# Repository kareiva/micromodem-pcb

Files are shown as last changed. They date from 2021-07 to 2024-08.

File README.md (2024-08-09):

# LY2EN-made MicroModem Arduino Nano shield

PCB and schematics for a very basic [MicroModem](https://unsigned.io/micromodem/) shield for Arduino Nano to use with Baofeng radios.

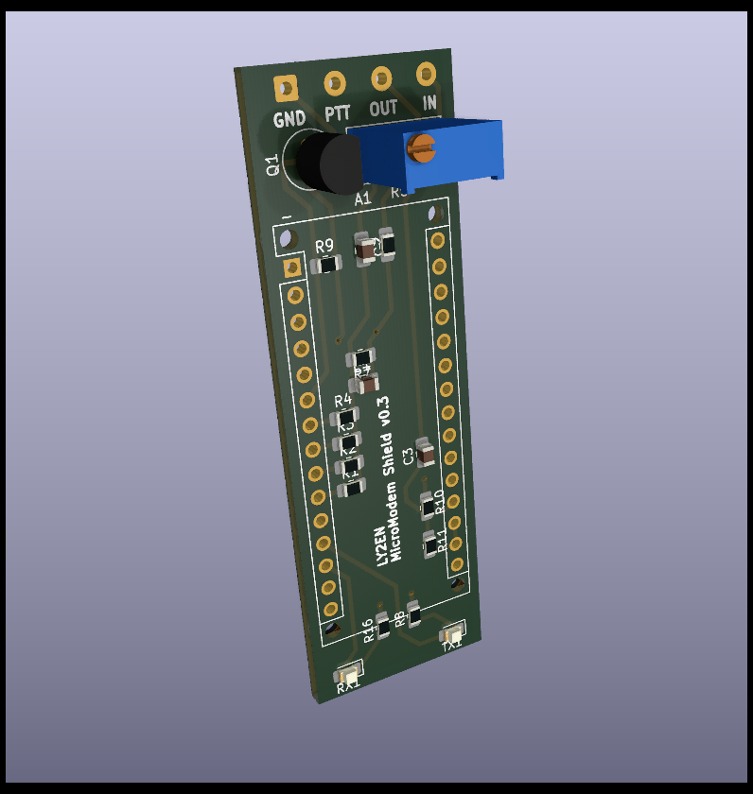
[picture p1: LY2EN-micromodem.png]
LY2EN-micromodem


## Disclaimer

This is experimental work. The authors do not hold any responsibility for any damage to your electronics components, wiring or other property when using this prototype. Use at your own risk.

## How to use

1. Upload the [MicroAPRS 3v KISS firmware](https://github.com/markqvist/MicroAPRS/raw/master/precompiled/microaprs-3v-kiss-latest.hex) to the Arduino Nano:

    avrdude -p m328p -c arduino -P /dev/ttyUSB0 -b 115200 -U flash:w:microaprs-3v-kiss-latest.hex

2. Plug the Arduino Nano into your Android phone's USB host

3. Launch [APRSDroid](https://aprsdroid.org/) 

    3.1 Select TNC (KISS) mode over USB. 
    
    3.2 Keep the baud rate at 9600.
    
4. Set the 3296W trimmer to something around 47kOhm. Your resistance might vary here. Once you're confident, you can replace it with a simple 47k resistor.

Verified working with both the MicroAPRS KISS and MicroAPRS SimpleSerial firmware for 3V.

## Cables

If you're not using a [Bluetooth SPP-C module](https://www.aliexpress.com/item/32998624269.html), a USB-C male to USB-A female adapter is required for recent Android smartphones.

Connect to Baofeng radio over [this cable](https://a.aliexpress.com/_mNhKQOm).

### Pinout
The Baofeng cable has two TRS (Tip, Ring, Sleeve) connectors.
#### 3.5mm
* Sleeve - PTT
* Ring - OUT
#### 2.5mm
* Sleeve - GND
* Tip - IN

## Features / Changelog

### Version 0.4
* Added pin hole connector for SPP-C Bluetooth module

### Version 0.3 (verified)
* Upgraded to KiCad version 6
* Fixed edge cut layer (Edge.Cuts)
* Re-rendered PCB 3D visual with ray tracing
* Added JLCPCB compatible BOM and CPL files
* Ordered test batch from JLCPCB :)
* **Verified working!**

### Version 0.2
* Traces widened from 0.25 to 0.5mm
* Added GND area fill on the back side
* Signature added :)

### Version 0.1
* Only the ANALOG_IN, ANALOG_OUT and PTT are exposed.
* PTT wiring has been done as per Baofeng schematics.
* Tested with 3.3V MicroModem's [SimpleSerial](https://github.com/markqvist/MicroAPRS/raw/master/precompiled/microaprs-3v-ss-latest.hex) and [KISS](https://github.com/markqvist/MicroModemGP/raw/master/precompiled/MicroModemGP-3v-kiss.hex) firmware.
* Assuming that RST, XTAL, SPI pins, the CH340 and the rest of stuff is on the Nano already
* Wiring is done for 3.3V, so make sure to use the 3.3V MicroModem hex (see above).

## TODO

* Replace Q1 with SMT version

## Authors

PCB made by Simonas Kareiva LY2EN (<ly2en@qrz.lt>) using KiCad and by looking at the [original schematics](https://unsigned.io/wp-content/uploads/2014/12/Schematic-1.pdf).

Inspiration by [Vilius LY3FF](https://github.com/vilisas/).

MicroModem originally by https://github.com/markqvist

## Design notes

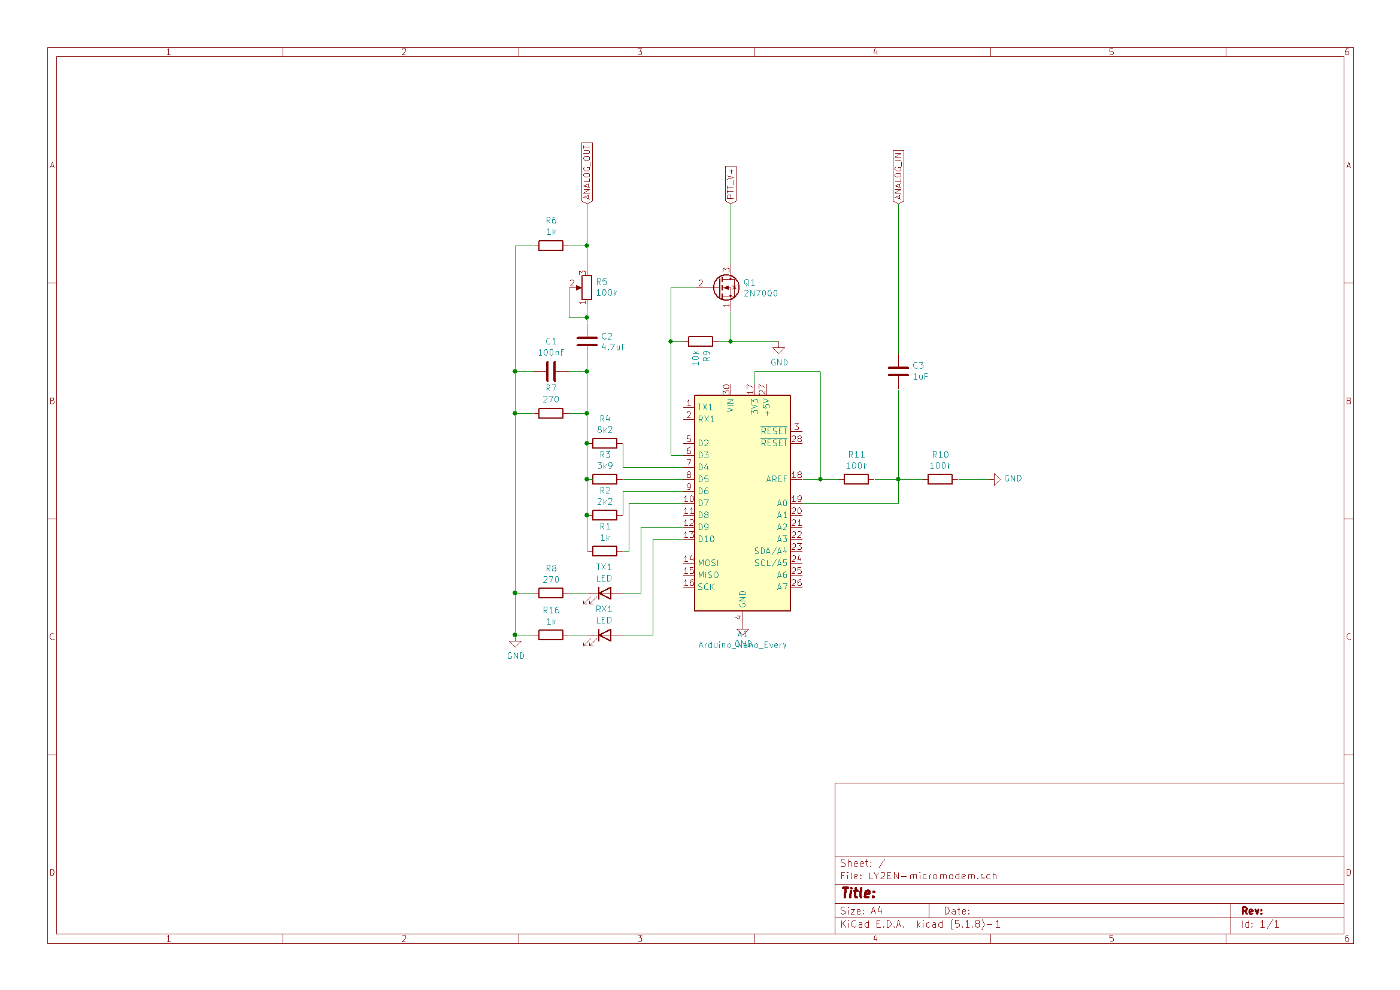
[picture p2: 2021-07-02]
LY2EN-micromodem-sch.png

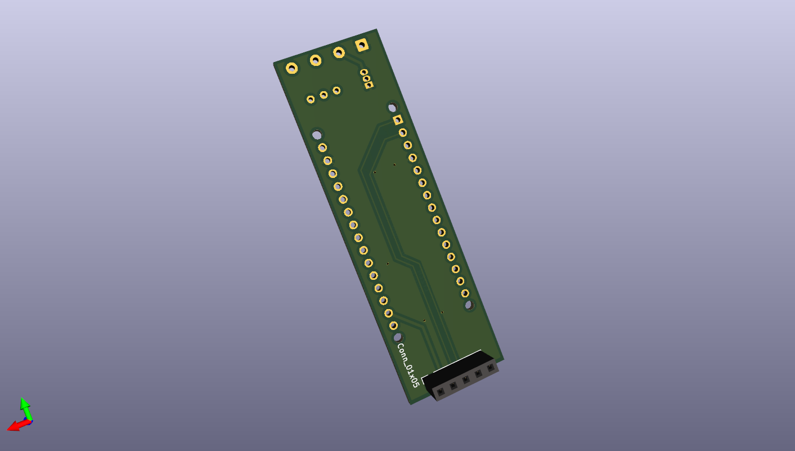
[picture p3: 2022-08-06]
LY2EN-micromodem-v0.4-back.png

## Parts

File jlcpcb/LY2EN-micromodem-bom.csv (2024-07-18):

Comment | Designator | Package | JLCPCB Part #（optional）
100nF | C1 | C_0805_2012Metric_Pad1.18x1.45mm_HandSolder
1uF | C3 | C_0805_2012Metric_Pad1.18x1.45mm_HandSolder
47k | R5 | R_0805_2012Metric_Pad1.20x1.40mm_HandSolder
270 | R7,R8 | R_0805_2012Metric_Pad1.20x1.40mm_HandSolder
100k | R11,R10 | R_0805_2012Metric_Pad1.20x1.40mm_HandSolder
1k | R16,R6,R1 | R_0805_2012Metric_Pad1.20x1.40mm_HandSolder
LED | TX1 | LED_0805_2012Metric_Pad1.15x1.40mm_HandSolder | C84256
LED | RX1 | LED_0805_2012Metric_Pad1.15x1.40mm_HandSolder | C2296
4.7uF | C2 | C_0805_2012Metric_Pad1.18x1.45mm_HandSolder
Arduino_Nano_Every | A1 | Arduino_Nano_WithMountingHoles
10k | R9 | R_0805_2012Metric_Pad1.20x1.40mm_HandSolder
2k2 | R2 | R_0805_2012Metric_Pad1.20x1.40mm_HandSolder
3k9 | R3 | R_0805_2012Metric_Pad1.20x1.40mm_HandSolder
8k2 | R4 | R_0805_2012Metric_Pad1.20x1.40mm_HandSolder
2N7000 | Q1 | TO-92_Inline | C9114

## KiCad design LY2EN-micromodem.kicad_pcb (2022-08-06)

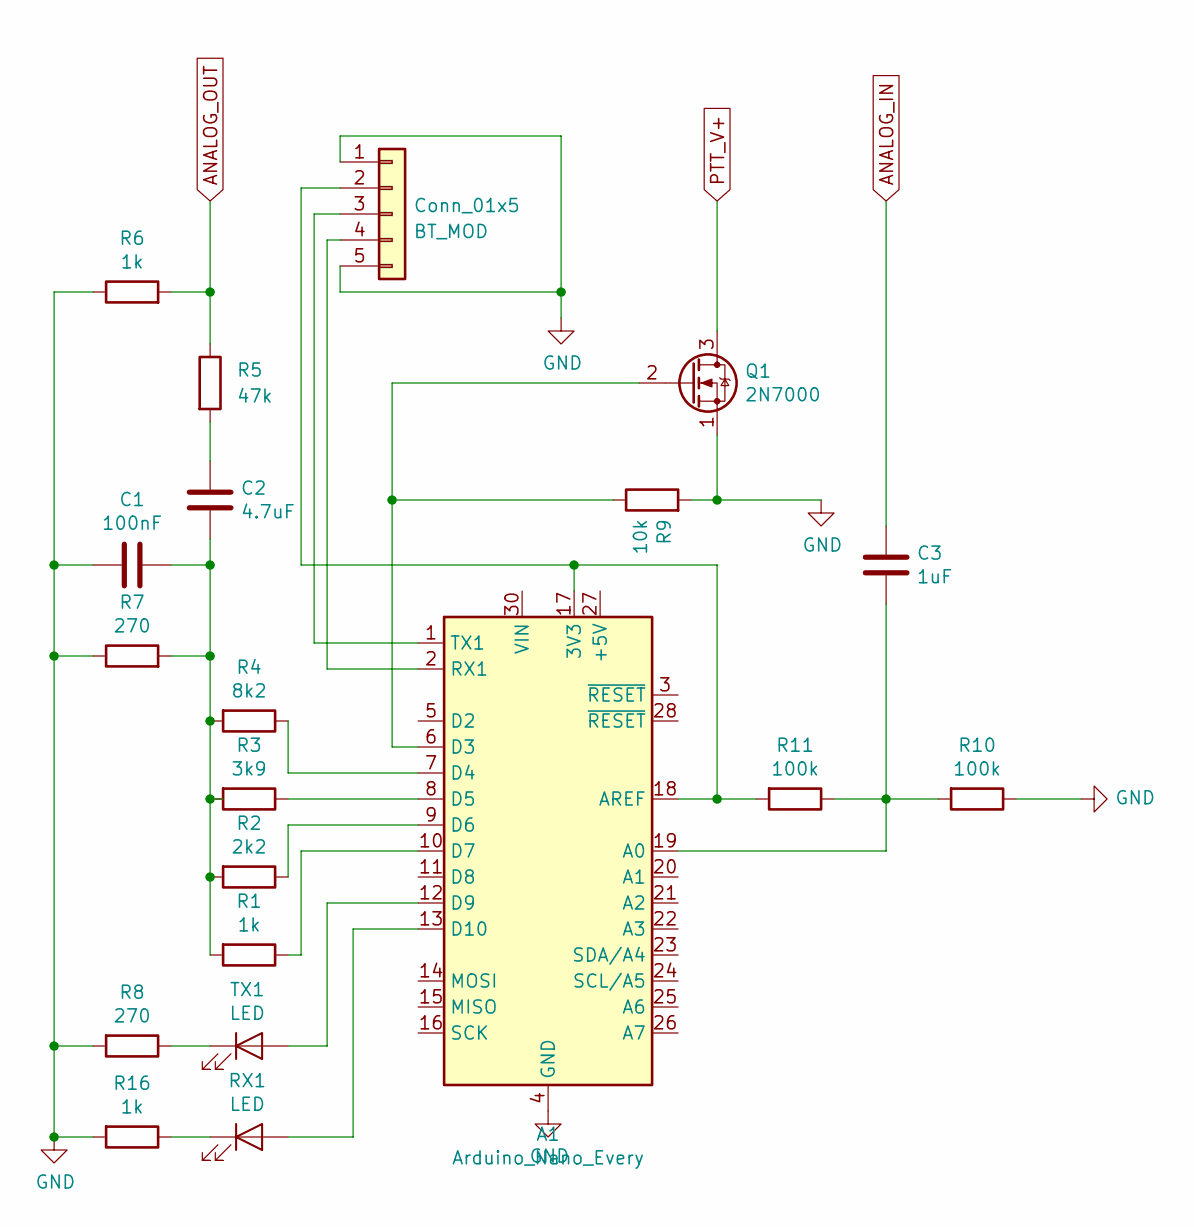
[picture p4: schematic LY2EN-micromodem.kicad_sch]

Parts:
A1: Arduino_Nano_Every; Arduino_Nano_WithMountingHoles
C1: 100nF; C_0805_2012Metric_Pad1.18x1.45mm_HandSolder
C2: 4.7uF; C_0805_2012Metric_Pad1.18x1.45mm_HandSolder
C3: 1uF; C_0805_2012Metric_Pad1.18x1.45mm_HandSolder
Conn_01x5: BT_MOD; PinSocket_1x05_P2.54mm_Vertical
Q1: 2N7000; TO-92_Inline
R1, R6, R16: 1k; R_0805_2012Metric_Pad1.20x1.40mm_HandSolder
R2: 2k2; R_0805_2012Metric_Pad1.20x1.40mm_HandSolder
R3: 3k9; R_0805_2012Metric_Pad1.20x1.40mm_HandSolder
R4: 8k2; R_0805_2012Metric_Pad1.20x1.40mm_HandSolder
R5: 47k; R_0805_2012Metric_Pad1.20x1.40mm_HandSolder
R7, R8: 270; R_0805_2012Metric_Pad1.20x1.40mm_HandSolder
R9: 10k; R_0805_2012Metric_Pad1.20x1.40mm_HandSolder
R10, R11: 100k; R_0805_2012Metric_Pad1.20x1.40mm_HandSolder
RX1: LED; LED_0805_2012Metric_Pad1.15x1.40mm_HandSolder
TX1: LED; LED_0805_2012Metric_Pad1.15x1.40mm_HandSolder

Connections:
ANALOG_IN: C3.2; also elsewhere on the board
ANALOG_OUT: R5.1, R6.2; also elsewhere on the board
GND: A1.4 (GND), A1.29 (GND), C1.2, Conn_01x5.1, Conn_01x5.5, Q1.1 (S), R6.1, R7.1, R8.2, R9.2, R10.1, R16.2; also elsewhere on the board
unnamed: A1.1 (TX1), Conn_01x5.3
unnamed: A1.2 (RX1), Conn_01x5.4
unnamed: A1.6 (D3), Q1.2 (G), R9.1
unnamed: A1.7 (D4), R4.1
unnamed: A1.8 (D5), R3.1
unnamed: A1.9 (D6), R2.1
unnamed: A1.10 (D7), R1.1
unnamed: A1.12 (D9), TX1.2 (A)
unnamed: A1.13 (D10), RX1.2 (A)
unnamed: A1.17 (3V3), A1.18 (AREF), Conn_01x5.2, R11.2
unnamed: A1.19 (A0), C3.1, R10.2, R11.1
unnamed: C1.1, C2.2, R1.2, R2.2, R3.2, R4.2, R7.2
unnamed: C2.1, R5.2
unnamed: R8.1, TX1.1 (K)
unnamed: R16.1, RX1.1 (K)
PTT_V+: Q1.3 (D); also elsewhere on the board

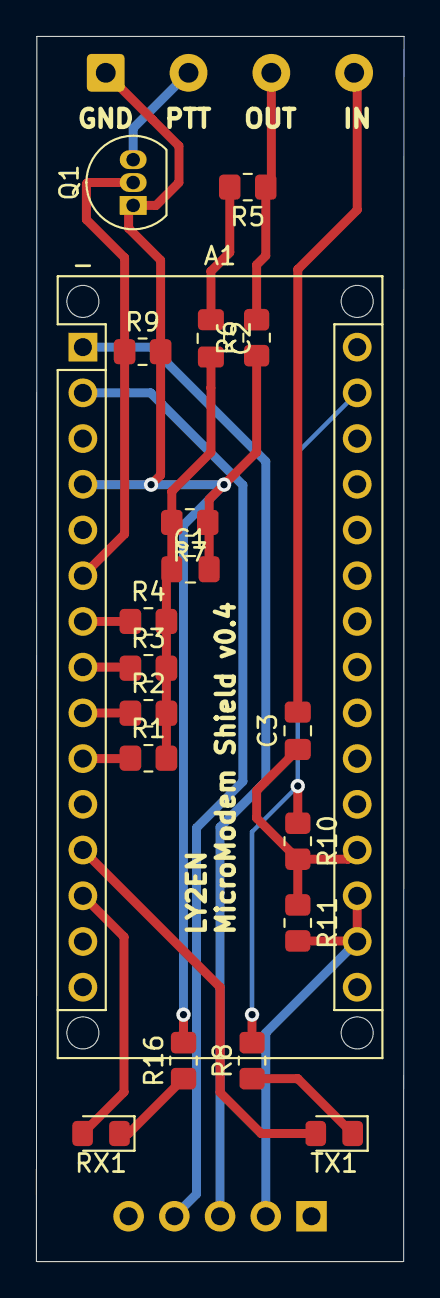
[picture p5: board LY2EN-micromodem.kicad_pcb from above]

Board: 2 copper layers, 20.4 x 68.1 mm, 21 parts (1 on the bottom side), 19 nets.

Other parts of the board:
_: SolderWire; SolderWire-0.5sqmm_1x04_P4.6mm_D0.9mm_OD2.1mm

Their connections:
ANALOG_IN: _.4; also elsewhere on the board
ANALOG_OUT: _.3; also elsewhere on the board
GND: _.1; also elsewhere on the board
PTT_V+: _.2; also elsewhere on the board

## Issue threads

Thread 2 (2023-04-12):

Where does the board get powered from?

TechnikWeber, 2023-04-12:
Maybe i misunderstood something, but where dies the board get powered from?
Does it get Power from the Baofeng itself or do i need always power it from USB (on Arduino)?
So if i need a portable version i would need an external battery?

kareiva, 2024-07-17:
From the README.md:

> 2) Plug the Arduino Nano into your Android phone's USB host

Of course you could get a 3-Volt battery to power it.

The current coming from the Baofeng jack is not enough to power the Arduino.

Closed 2024-08-07.

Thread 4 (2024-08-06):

Cable Wiring

ido1990, 2024-08-06:
Hi!
Thank you for this nice project.
I just finished soldering everything but I'm not sure how to connect the Baofeng cable.
The colors on my cable are different and the diagrams found online didn't help much.
Do you know what color connected to what 3.5/2.5mm contact?
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
Thank you!

kareiva, 2024-08-06:
SPK and MIC on your diagram go to IN and OUT respectively. You should use the audio (not data) ground, also for the last one, you can check if the PTT works by shorting the circuit on your cable before soldering it.

ido1990, 2024-08-07:
Thank you for responding,
The only grounds I can think of is MIC- and SPK- but SPK- is also the data ground.
As far as I know, the PTT is triggered by connecting the two sleeves together (mentioned in the picture by PTT).
So according to this, I would need to connect like this:
MIC+ --> OUT
SPK+ --> IN
MIC-/Rx Data/PTT --> PTT
GND --> SPK-/PTT/GND Data

Seems correct?

kareiva, 2024-08-07:
Although it seems to be correct, please test this before soldering. A simple osciloscope will show you if the SPK/GND combination produces the expected low frequency signals.

I take no responsibility for wiring issues that might damage your equipment :)

ido1990, 2024-08-07:
Of course.
I will test everything before soldering :)
Thank you!

ido1990, 2024-08-07:
Ok,
So everything is working except of the PTT.
When the MicroModem is off and the Baofeng is connected nothing happens but in the moment the MM gets power, the PTT is always on.
Do you have any clue what could go wrong?

kareiva, 2024-08-07:
Check with a multimeter if the micromodem shorts between ptt and gnd during transmission.

ido1990, 2024-08-07:
Yes it does.
I just tested it when the Baofeng was off.
When I turn it on, it shorts the PTT. Weird.

kareiva, 2024-08-07:
I never had any issues with PTT, it worked quite well without any tweaking. I even have a working board somewhere with a Baofeng cable, if you are out of options, I could ship that to you.

ido1990, 2024-08-07:
That's very generous, that you!
But I think I would like to have something I built myself if I can :)
If you have time and patience, It would help me to know what's the voltage should be across PTT and GND.
I see 1.2mv which is not the same as when the radio is on (1.6v) so maybe that's the issue.

ido1990, 2024-08-07:
Found the culprit.
The 2N7000 was bad.
Now it works.
Thank you for your help!

kareiva, 2024-08-07:
Congrats! So the issue is closed? Would you like to update the docs on the wiring?

ido1990, 2024-08-07:
Yes.
I will gather all the data from my project and update.

Closed 2024-08-07.

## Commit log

2021-04-29 Initial commit + README
    [LY2EN-micromodem.kicad_pcb, LY2EN-micromodem.sch]
2021-04-29 Shrink SMD components down from 1812 to 0805
    [LY2EN-micromodem.sch]
2021-04-29 PCB version 0.1
    [LY2EN-micromodem.kicad_pcb]
2021-04-30 Improved PCB layout: 0.5mm tracks and GND zone
    [LY2EN-micromodem.kicad_pcb]
2021-07-02 Add exported schematics in PNG format
2022-05-09 Upgrade to KiCad version 6
    [LY2EN-micromodem.kicad_pcb, LY2EN-micromodem.kicad_sch]
2022-05-09 Bump to version 0.3
    [LY2EN-micromodem-bom.csv, LY2EN-micromodem.kicad_pcb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]
2022-07-18 Add Bluetooth SPP-C serial passthrough support
    [LY2EN-micromodem.kicad_pcb, LY2EN-micromodem.kicad_sch]
2022-07-18 Replace potentiometer with static 47k resistor
    [LY2EN-micromodem-bom.csv, LY2EN-micromodem.kicad_pcb, LY2EN-micromodem.kicad_sch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]
2022-07-18 Fix bottom zone fill
    [LY2EN-micromodem.kicad_pcb]
2024-07-18 Removed R9 from line 4
    Removed R9 from line 4
    [LY2EN-micromodem-bom.csv]
2024-08-09 Update README.md (#5)
    More information about the Baofeng cable pinout
